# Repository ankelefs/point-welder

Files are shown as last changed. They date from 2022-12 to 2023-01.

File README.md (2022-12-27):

# POINT WELDER 

<p>
	Current version: <b>V1</b><br>
	Planned next version: <b>V2</b> (IN PROGRESS)
</p>

<h2>Information ℹ️</h2>
<p>
	This is a home made point welder circuit that easily can be attached to a 12 V car battery to provide a good weld between two, thin, metal sheets, i.e. for battery cell connections.
</p>

<h2>Specifications ℹ️</h2>
<p>
	This section provides a summary of the different versions.
</p>

<h3>Point Welder V2 🟡</h3>

<h3>Point Welder V1 🟢</h3>
<p>
	Point Welder V1 proved that the circuit works (without fuses blowing and batteries exploding). It has a large 3D-printed housing containing everything excluding the cables for attaching to the car battery and for welding. It has a cascade of switches and relays to reliably control the huge current when operating. An Arduino Nano Every is the brain behind the circuit and is powered by the attached battery through a 12 V --> 5 V buck converter.<br><br>
	The cable from the connected battery's positive terminal goes through a 300 A fuse before anything else to ensure a redundant fail-safe. Also, the largest relay (rated at 200 A continuous draw) has a switch that needs to be on before it can work, as an additional safety feature.
</p>

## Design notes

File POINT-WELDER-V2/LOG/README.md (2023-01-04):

### 08.12.22
Tested the circuit (V1) for the first time. 
I have been too afraid to "play" with batteries, but today I tested it, and it works. 
There are some improvements that can be made, for sure, but the circuit did not blow up, nor did the battery - I call that a win. 
The weld between two thin plates was very strong.
I wish to develop a version 2 (V2) of the circuit to improve certain aspects of it, and then test it thuroughly.

------------
### 18.12.22
Worked on schematics and PCB.

Needs to be done:
* ✅ Make sure all dimensions are correct (headers, OLED-screen).
* ✅ Make sure the schematic is "usable".
* ✅ Export PCB to Fusion 360 to start 3D-modelling.
* ✅ Import all relevant documents to GitHub-folder (datasheets, circuit-schematics/-figures ++).

------------
### 20.12.22
Worked on schematics:
* Changed DRIVER-MOSFET to be low-side-implemented (for switching).
* Changed POWER-MOSFET to be high-side-implemented (for giving power). ❗️ Need to double check - it may have to be low-side-implemented if weld-resistance is higher than Rds of MOSFET (Thanks for feedback, Sindre).

Worked on board layout (PCB):
* Added holes for mounting.
* Finalized trace widths and the general layout.

Worked on 3D housing-model:
* A rough skecth is now complete.

Needs to be done:
* ❌ Implement Miro with GitHub
* ✅ Check schematics and maybe change POWER-MOSFET to be low-side-implemented.
* ❌ 3D: Add screw holes at the top of the pillars (topside) for mounting components together.
* ❌ 3D: Add bracket for mounting OLED-display (nicely).
* ⚠️ 3D: Add spacers for PCB to rest upon and be fastened to with screws.

------------
### 27.12.22
Schematics:
* Removed capacitor before buck converter. Reason: BAT+ signal need good clearing - caused problems and not much needed.
* Changed to low-side configuration for power-MOSFET.
* Completed.

PCB:
* Almost completed.

To do:
* ⚠ A new 3D-model that encapsulates it more and is more aesthetic.
* ⚠️ 3D-model needs implemented fastener for cables and OLED-display.
* ✅ Edit README-files.
  
------------
### 30.12.22
Schematics: 
* Renumbered items.
 
PCB:
* Finishing touches. 
* Ordered lacking components: IRLB3034 (Digi-Key) and 10k potmeter (Digi-Key). Total order sum: 568,20 kr (IRLB3034: 7 pcs, potmeter: 2 pcs). 🥳

To do:
* ✅ Look at potmeter datasheet and change pin location so that the rotary dial sticks out "perfectly" from the enclosure.
* ✅ Order PCBs. --> Finish 3D-model.

------------
### 31.12.22
PCB:
* Changed position of potentiometer.
* Changed position and dimension (3 mm) of holes for fastening to a base (enclosure).
* Ordered! 🥳

PCB top-view

I see from the picture that the names/values of the resistors are not in it. They should be moved to either the tValue or tName layer to be printed on the silkscreen. But this is not a big concern since it is a fairly easy electronic schematic/design.

Only need to design the enclosure (prefarably before the PCBs arrive) and make/assemble it. Need to figure out if it should be made with fully 3D-printed parts or if the design is nicer if it's made with acrylic glass. 

------------
### 01.01.23
Finished the 3D-model design. It only needs a few minor adjustments with regards to the cable dimensions (need to make sure the holes are big enough).

3D-model

* ⚠️ Need to find which cables to buy and double check dimensions in 3D-model.
* ⚠️ Need to then make an ergonomic holder for the weld tips.
* ⚠️ Need to find properly sized crocodile clamps for the cable ends that go to the battery.

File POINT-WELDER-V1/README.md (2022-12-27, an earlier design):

# POINT WELDER V1

<p>
	Point Welder V1 proved that the circuit works (without fuses blowing and batteries exploding). It has a large 3D-printed housing containing everything excluding the cables for attaching to the car battery and for welding. It has a cascade of switches and relays to reliably control the huge current when operating. An Arduino Nano Every is the brain behind the circuit and is powered by the attached battery through a 12 V --> 5 V buck converter.<br><br>
	The cable from the connected battery's positive terminal goes through a 300 A fuse before anything else to ensure a redundant fail-safe. Also, the largest relay (rated at 200 A continuous draw) has a switch that needs to be on before it can work, as an additional safety feature.
</p>

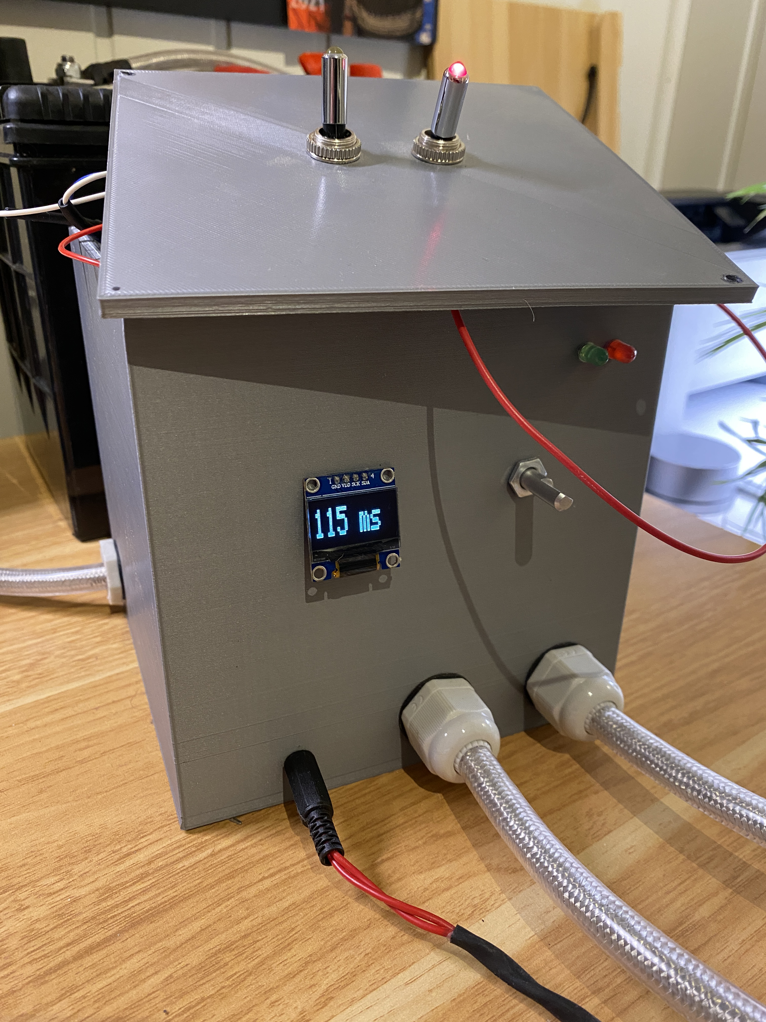
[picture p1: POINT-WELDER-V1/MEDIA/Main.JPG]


<b>Pros:</b>
<ul>
	<li>✅ Fully operational with connection to only one (sufficently powerful) 12 V battery.</li>
	<li>✅ Easy to operate.</li>
	<li>✅ Safe and secure with redundant fail-safes.</li>
</ul>

<b>Cons:</b>
<ul>
	<li>❌ Large housing.</li>
	<li>❌ Not very nice looking.</li>
	<li>❌ Stiff cables, making it hard to operate.</li>
	<li>❌ Not modular with regards to external cables.</li>
	<li>❌ Impractical connectors for external battery.</li>
</ul>

<b>Improvements:</b>
<ul>
	<li>🟡 Time setting range from 10 to 100 ms instead of 50 to 200 ms.</li>
	<li>🟡 Custom made PCB for the electronics.</li>
	<li>🟡 Smaller, and nicer looking, housing.</li>
	<li>🟡 Second (smallest of the relays) relay powered by battery and not Arduino.</li>
	<li>🟡 Improved time setting code robustness in endpoints to end "flickering".</li>
	<li>🟡 Working LEDs.</li>
	<li>🟡 Detachable cables.</li>
	<li>🟡 Cables with softer isolation and multi-threaded.</li>
	<li>🟡 Crocodile connectors.</li>
</ul>

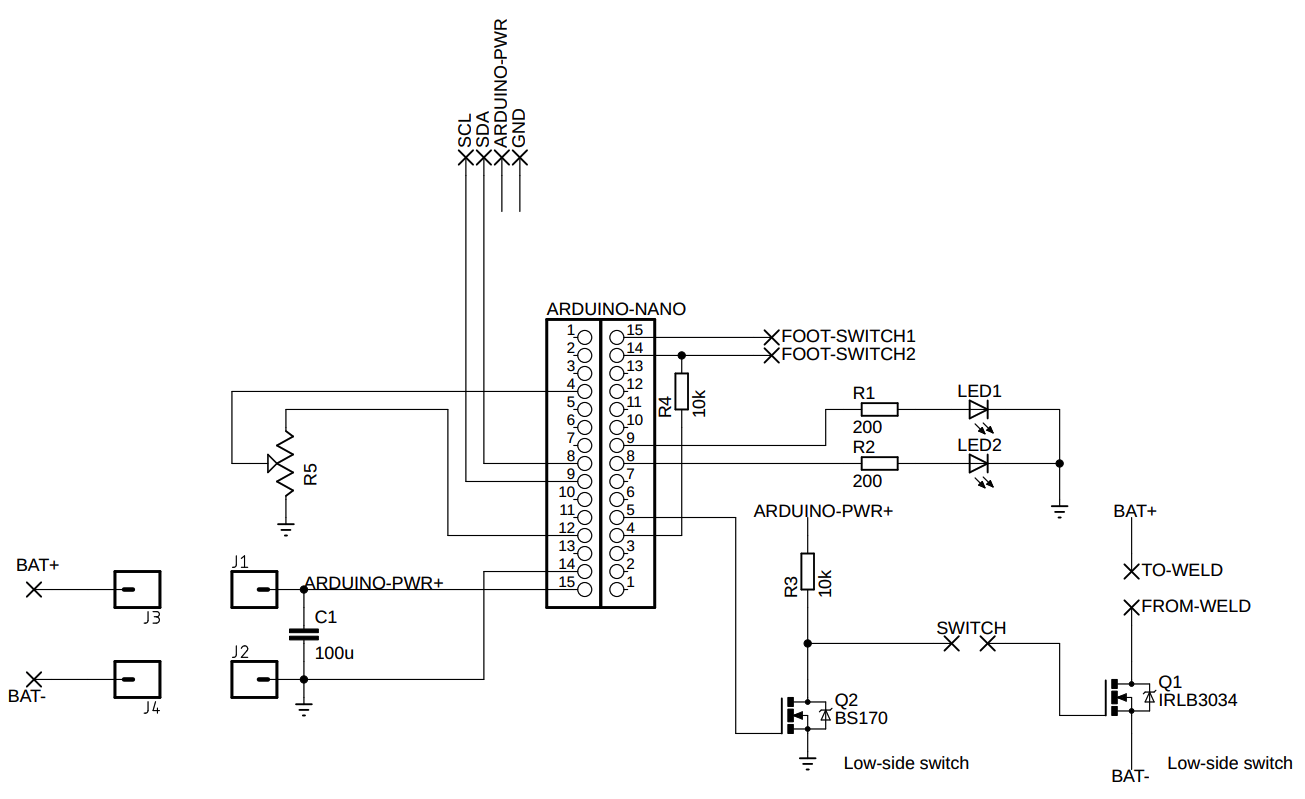
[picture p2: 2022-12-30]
POINT-WELDER-V2/HARDWARE/Point-Welder-V2-Schematics.png

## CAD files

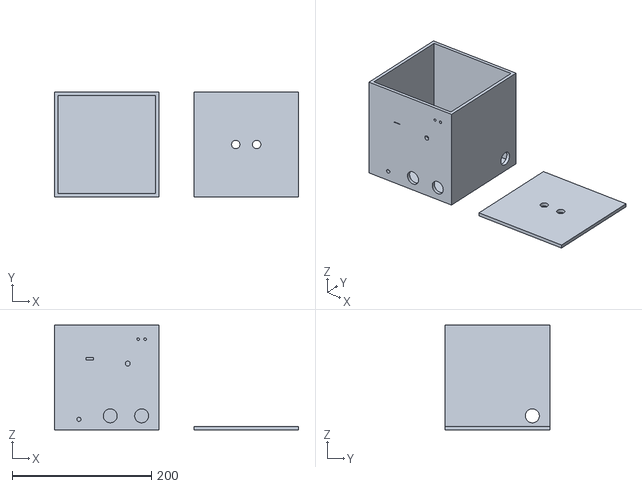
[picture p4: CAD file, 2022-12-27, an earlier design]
POINT-WELDER-V1/3D-MODEL/cad.stl
350.0 x 150.0 x 150.0

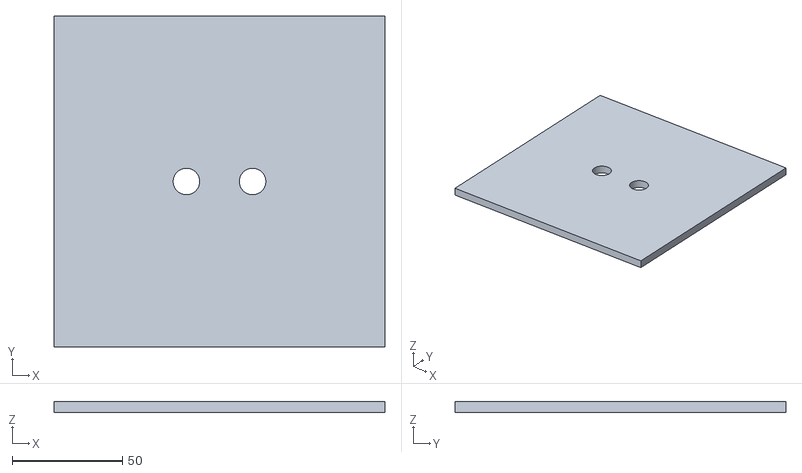
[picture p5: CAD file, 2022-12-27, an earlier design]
POINT-WELDER-V1/3D-MODEL/lid.stl
150.0 x 150.0 x 5.00

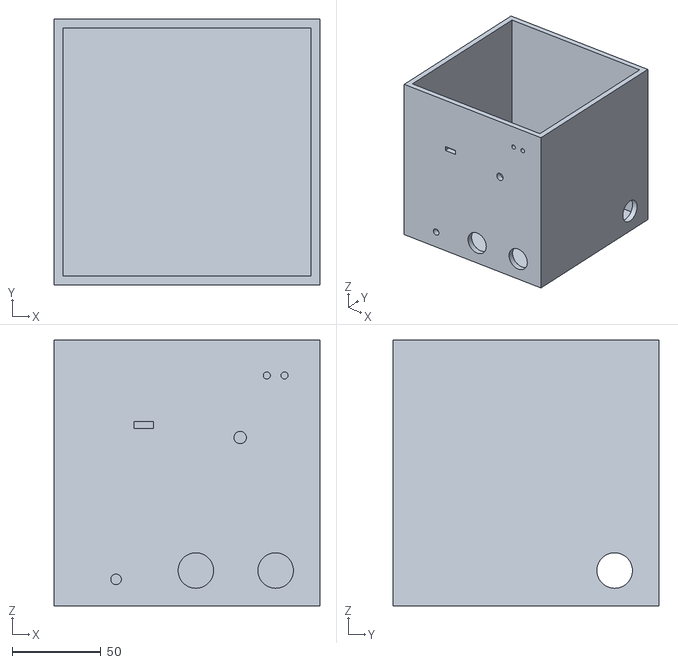
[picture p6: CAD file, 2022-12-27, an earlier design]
POINT-WELDER-V1/3D-MODEL/box.stl
150.0 x 150.0 x 150.0

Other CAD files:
POINT-WELDER-V1/3D-MODEL/cad.scad

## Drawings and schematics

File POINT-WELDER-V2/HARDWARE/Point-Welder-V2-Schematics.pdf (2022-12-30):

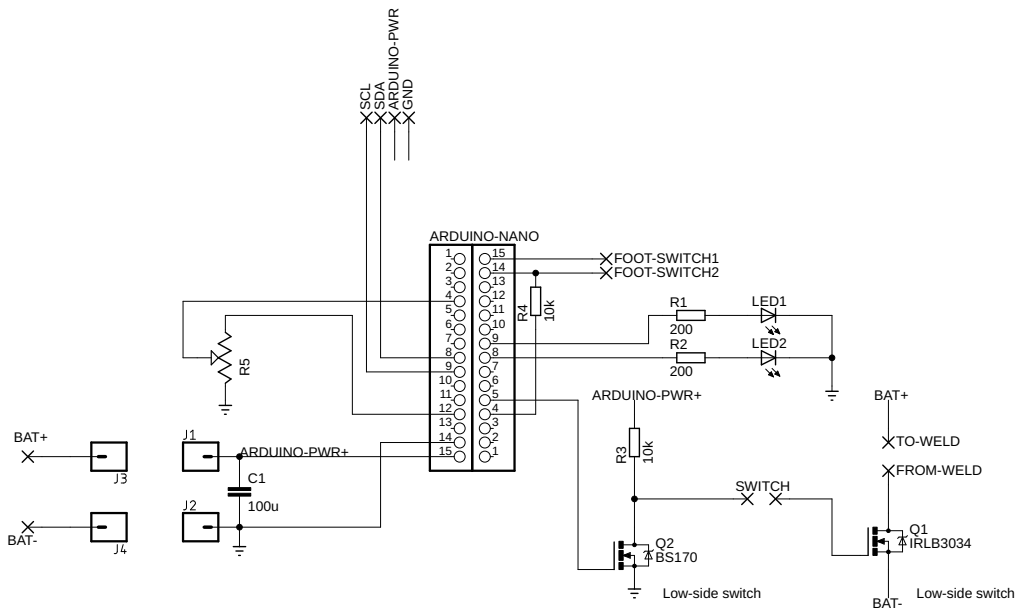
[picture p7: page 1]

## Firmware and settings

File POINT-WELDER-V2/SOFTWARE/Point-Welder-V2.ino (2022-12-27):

/***************************************************
    HJERNEN ("The Brain")

    Functionality:
    - Adjust value of ms (miliseconds)
    - Relay-programming
    - Button for opening the relay 
    - OLED screen showing ms value
    - Potentiometer for changing the ms value
***************************************************/
#include <SPI.h>
#include <Wire.h>
#include <Adafruit_GFX.h>
#include <Adafruit_SSD1306.h>

#define SCREEN_WIDTH 128  // OLED oled width,  in pixels
#define SCREEN_HEIGHT 32  // OLED oled height, in pixels

Adafruit_SSD1306 oled(SCREEN_WIDTH, SCREEN_HEIGHT, &Wire, -1);  // Declare SSD1306 oled connected to I2C


/*** Global variables ***/
// Constants
const int msPIN = A0;                   // Analog INPUT value of potentiometer at pin 19 (A0)
const int impulseVoltagePIN = 12;       // Impulse switch OUTPUT at pin 15 (D12)
const int impulseReadPIN = 11;          // Impulse switch INPUT (read) at pin 14 (D11)
const int weldSignalPIN = 2;            // BS170 gate OUTPUT signal at pin 5 (D2)
const int LED_G = 8;                    // Green LED OUTPUT (D8)
const int LED_R = 9;                    // Red LED OUTPUT (D9)
const long millisInterval = 500;        // 500 ms
const int N = 31;                       // Number of values in compArray

// Variables and start-values
bool weld = false;                  // Boolean help variable with start-value
bool updateOLED_bool = false;       // Boolean help variable with updating the OLED
int msVAL = 0;                      // Default start ms-value  
unsigned long previousMillis = 0;   // Timing
int compArray[N];                   // Helper array with 30 ints


/*** Setup ***/
void setup() {
  // Array setup
  compArray[0] = 50;  // First index value is 50 (ms)
  for (unsigned int i = 1; i < N; i++) {
    compArray[i] = compArray[i-1] + 5;
  }

  // PIN setup
  pinMode(impulseReadPIN, INPUT);
  pinMode(impulseVoltagePIN, OUTPUT);      
  pinMode(weldSignalPIN, OUTPUT);           
  pinMode(msPIN, INPUT);    
  pinMode(LED_BUILTIN, OUTPUT); 
  pinMode(LED_G, OUTPUT);
  pinMode(LED_R, OUTPUT);               

  // Interrupt setup
  attachInterrupt(digitalPinToInterrupt(impulseReadPIN), triggerWeld, RISING);  // Triggers when pin goes from LOW to HIGH

  // OLED oled and startup
  // initialize OLED oled with address 0x3C for 128x32
  // Don't set pinMode when dealing with OLED (!), it uses I2C
  if (!oled.begin(SSD1306_SWITCHCAPVCC, 0x3C)) {
    Serial.println(F("[ERROR] SSD1306 allocation failed"));
    while (true);
  }
  delay(2000);
  oled.clearDisplay();
  oled.display();

  // Initial setup
  digitalWrite(impulseVoltagePIN, HIGH);  // Set +5V on the pin
  digitalWrite(LED_G, HIGH);
}


/*** Main loop ***/
void loop() {
  // Welding
  if (weld) {
    digitalWrite(LED_G, LOW);
    digitalWrite(LED_R, HIGH);
    digitalWrite(LED_BUILTIN, HIGH);      // Built-in LED indicator
    digitalWrite(weldSignalPIN, HIGH);    // Start weld - keep close to delay() for accuracy
    delay(msVAL);                         // Weld time
    digitalWrite(weldSignalPIN, LOW);     // Stop weld
    digitalWrite(LED_BUILTIN, LOW);
    digitalWrite(LED_R, LOW);
    digitalWrite(LED_G, HIGH);
    delay(1000);                          // Extra delay to ensure no double-interrupt on same button-push

    // Need to set weld = false here to ensure no double-interrupt-calling. This cooperates with the previous delay() to ensure only one weld each time the button is (quickly) pressed
    weld = false;                         // Set weld to false for next iteration
  }

  // Update ms-value
  msUpdate();                // Update ms value and OLED print settings
  oled.display();            // Update OLED display
}

/*** Functions ***/
// Interrupt handler
void triggerWeld() {
  weld = true;           
}

// Update ms and OLED
void msUpdate() {
  msVAL = analogRead(msPIN);                // Read analog signal 
  msVAL = map(msVAL, 0, 1023, 50, 203);     // Update msVAL and map analog input to between 50-200 ms

  compareWithArray();                       // Map value again to get steps and more stable ms value
  updateOLED();                             // Update OLED print settings
}

// Compare value and map to steps from compArray
void compareWithArray() {
  for (unsigned int i = 1; i < N; i++) {
    if (msVAL > compArray[i-1] && msVAL < compArray[i]) {
      int diffFloor = msVAL - compArray[i-1];
      int diffCeil = compArray[i] - msVAL;

      if (diffFloor > diffCeil) {
        msVAL = compArray[i];
      } else {
        msVAL = compArray[i-1];
      }
    }
  }
}

// OLED
void updateOLED() {
  oled.clearDisplay();
  oled.setTextSize(3);        
  oled.setTextColor(WHITE);      
  oled.setCursor(0, 5);
  oled.print(msVAL);
  oled.print(" ms");
}

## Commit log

2022-12-20 Schematic logo
2022-12-27 V1 files upload
    [box.stl, cad.scad, cad.stl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]
2022-12-30 Work session
    [Point-Welder-V2-Schematics.sch]
